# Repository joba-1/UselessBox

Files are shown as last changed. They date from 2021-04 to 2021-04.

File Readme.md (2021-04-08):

# Useless Box

A box with a switch.

If you dare to flip the switch on, the box will immediatelly flip the switch back off.

Project includes code for an STM32L0 chip, STL files to 3d-print the box and the wiring diagram.
Compile and flash with the STM32CubeIDE (I used v1.5).
Code features: PWM duty cycle, deep sleep/standby, wakeup via interrupt pin
 
What you will need (besides basic soldering equipment and a 3d printer):

* STM32L0F4 chip or similar power saving cpu (and an ST-Link programming adapter for flashing)
* Servo SG90 (motor works with 5-6V but pwm data only needs 3V)
* Switch with >2cm long lever
* LED (if you want an ON indicator)
* 3 10k resistors
* 2 2x1.5V AAA battery holders
* Wire
* TSSOP20 to 0.25in pin spacing adapter PCB (directly soldering wires on adjacent CPU pins would be demanding...)

2021, Joachim Banzhaf

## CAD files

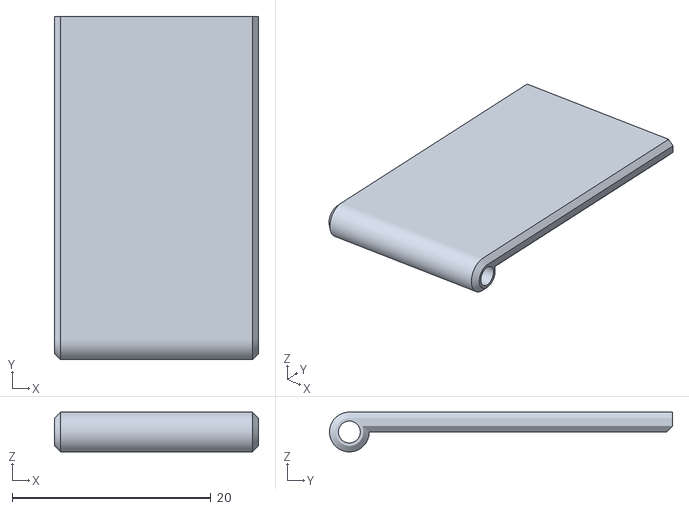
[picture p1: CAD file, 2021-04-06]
print3d/UselessBox-Deckel.stl
20.5 x 34.5 x 4.00

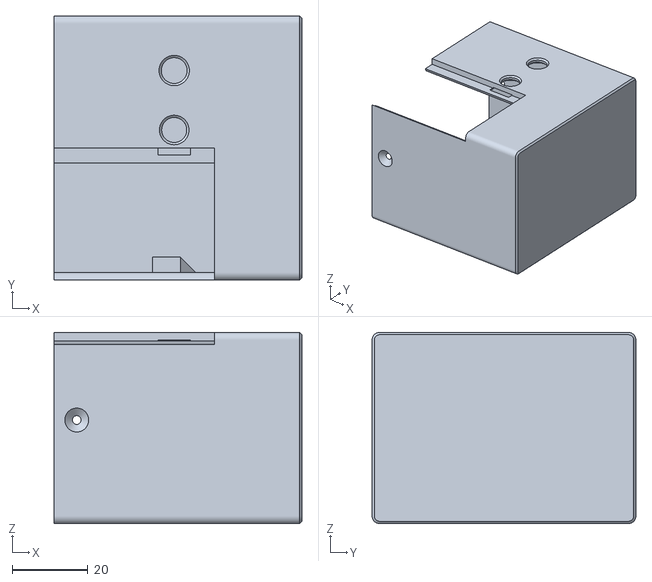
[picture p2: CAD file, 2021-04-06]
print3d/UselessBox-Gehäuse.stl
65.4 x 69.6 x 50.4

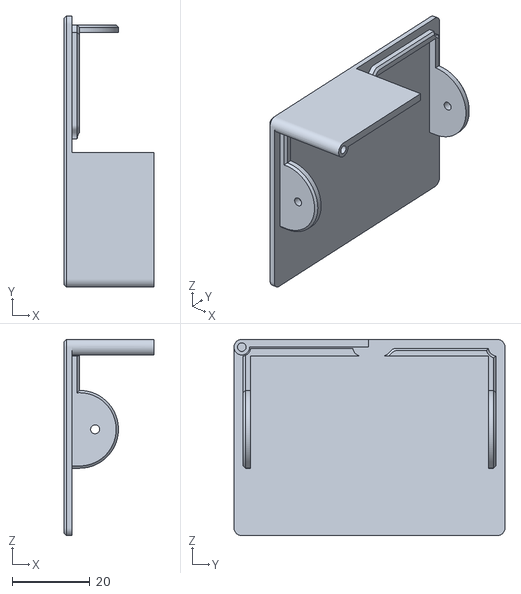
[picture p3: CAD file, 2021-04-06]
print3d/UselessBox-Seitenwand.stl
23.1 x 69.6 x 50.4

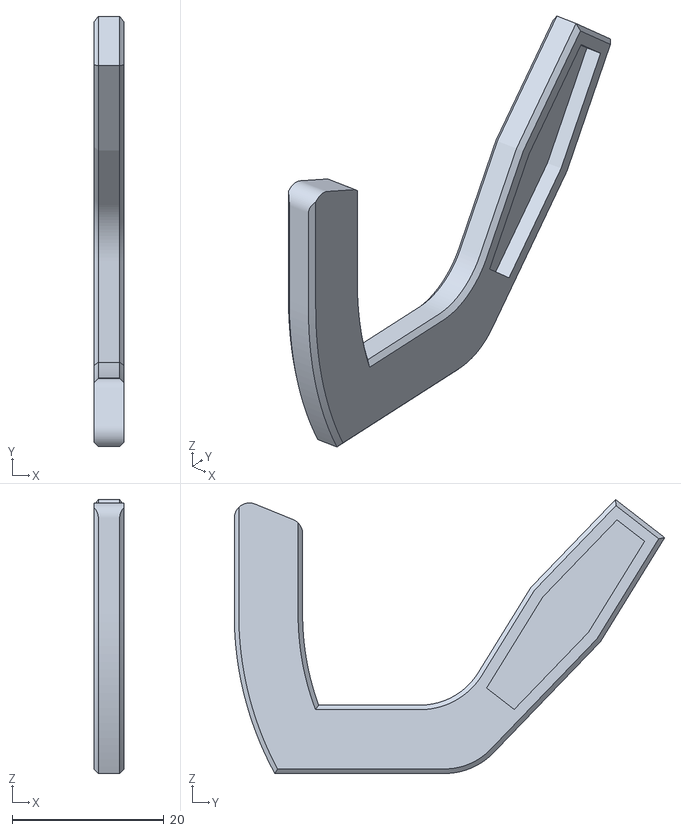
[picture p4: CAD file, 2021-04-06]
print3d/UselessBox-Arm.stl
4.00 x 56.6 x 36.1

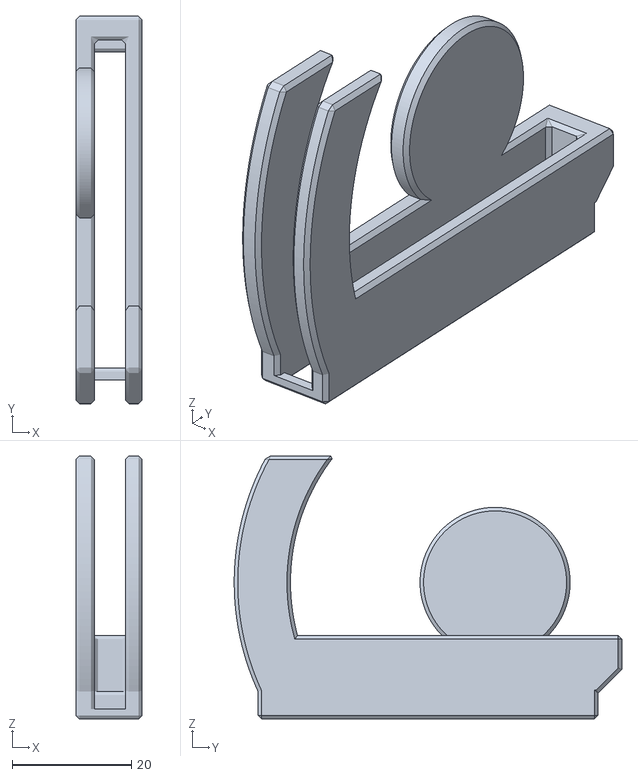
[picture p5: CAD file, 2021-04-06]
print3d/UselessBox-Führung.stl
11.1 x 65.0 x 44.1

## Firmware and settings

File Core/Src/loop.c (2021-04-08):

// Arduino style setup() and loop() to get away from generated main.c

#include "pwm.h"
#include "loop.h"

#include "print.h"
#include "power.h"
#include "millis.h"

// adapt to your servo and mechanical setup
#define SWITCH_POS 200
#define HIDE_POS -710

void setup(void) {
  millis_setup();

  LL_GPIO_SetOutputPin(LED_GPIO_Port, LED_Pin);

  print_str("\nUselessBox 1.1 " __DATE__ " " __TIME__ "\n");

  if (init_power()) {
    print_str("Wakeup\n");
  } else {
    print_str("Reset\n");
  }
}

// pos in promille 0-1000, negative in other direction
uint32_t pos2duty(int32_t pos) {
  const uint32_t min_duty = MIN_DUTY - 700; // 700: valid for my servo
  const uint32_t max_duty = 2 * MIN_DUTY + 300; // 300: valid for my servo

  return (pos + 1000) * (max_duty - min_duty) / 2000 + min_duty;
}

// Set servo to given position and return ms until pos is reached
uint32_t servo_pos(int32_t pos) {
  static const uint32_t HALF_SWEEP_MS = 700; // my servos half sweep
  static const int32_t NO_POS = 0xffff;
  static int32_t prev_pos = NO_POS;

  pwm_duty(0, pos2duty(pos));

  uint32_t ms = 0;
  if (prev_pos == NO_POS) {
    ms += HALF_SWEEP_MS;
    prev_pos = 0;
  }
  int32_t diff_pos = prev_pos - pos;
  if (diff_pos < 0)
    diff_pos = -diff_pos;
  ms += diff_pos * HALF_SWEEP_MS / 1000;
  prev_pos = pos;

  return ms;
}

void loop(void) {
  uint32_t now = millis();
  if (now > 1000) {
    pwms_on();

    // switch pos and back to hide pos as fast as possible
    delay(servo_pos(SWITCH_POS));

    LL_GPIO_ResetOutputPin(LED_GPIO_Port, LED_Pin);

    delay(servo_pos(HIDE_POS));

    pwms_off();

    print("Uptime", now, ": ");
    print_str("Sleeping\n");
    standby();

    delay(1000);
    print("Uptime", millis(), ": ");
    print_str("Sleep failed\n");
    reboot();

    while (1)
      ;
  }
}

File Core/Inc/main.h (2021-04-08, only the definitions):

#define MAX_DUTY 41940
#define MIN_DUTY 2082
#define TX_Pin LL_GPIO_PIN_1
#define TX_GPIO_Port GPIOA
#define PWM_Pin LL_GPIO_PIN_2
#define PWM_GPIO_Port GPIOA
#define LED_Pin LL_GPIO_PIN_4
#define LED_GPIO_Port GPIOA
#define NVIC_PRIORITYGROUP_0         ((uint32_t)0x00000007) /*!< 0 bit  for pre-emption priority,
#define NVIC_PRIORITYGROUP_1         ((uint32_t)0x00000006) /*!< 1 bit  for pre-emption priority,
#define NVIC_PRIORITYGROUP_2         ((uint32_t)0x00000005) /*!< 2 bits for pre-emption priority,
#define NVIC_PRIORITYGROUP_3         ((uint32_t)0x00000004) /*!< 3 bits for pre-emption priority,
#define NVIC_PRIORITYGROUP_4         ((uint32_t)0x00000003) /*!< 4 bits for pre-emption priority,

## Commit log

2021-04-06 add stl files for 3d printing of the housing
    [UselessBox-Arm.stl, UselessBox-Deckel.stl, UselessBox-Führung.stl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]
2021-04-08 remove unused servo power switch
2021-04-08 add wiring schematics
    [UselessBox.kicad_pcb, UselessBox.sch]

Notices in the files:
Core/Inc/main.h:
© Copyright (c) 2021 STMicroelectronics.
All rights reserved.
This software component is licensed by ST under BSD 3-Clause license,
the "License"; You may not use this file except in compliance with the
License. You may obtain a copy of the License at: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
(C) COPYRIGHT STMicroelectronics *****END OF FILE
